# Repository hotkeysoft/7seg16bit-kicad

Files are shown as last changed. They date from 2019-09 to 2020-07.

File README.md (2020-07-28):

# Six-digit seven-segment indicator for 16 bit values
Rev A August 2019

- ATmega8535 microcontroller running at 8MHz (internal clock)
- 3x2 digit 7-segment display
- Configurable modes via jumpers:
  - Decimal / HEX mode
    - Signed Decimal (-32768-32767)
    - Unsigned Decimal (0-65535)
    - Hexadecimal (0-FFFF)
  - Latch mode
    - Latch value on L->H transition
    - Latch value on H->L transition
    - Unlatched (live display)

Images
============
|Front | Back |
|---|---|
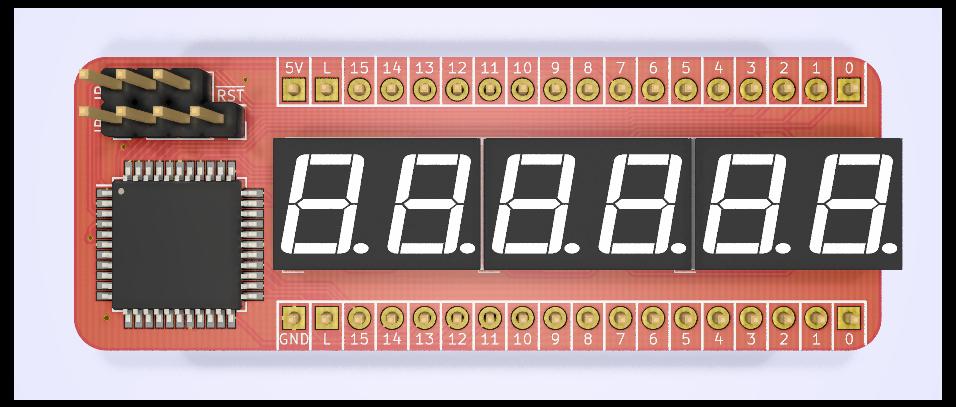
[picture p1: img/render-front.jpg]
Render Front
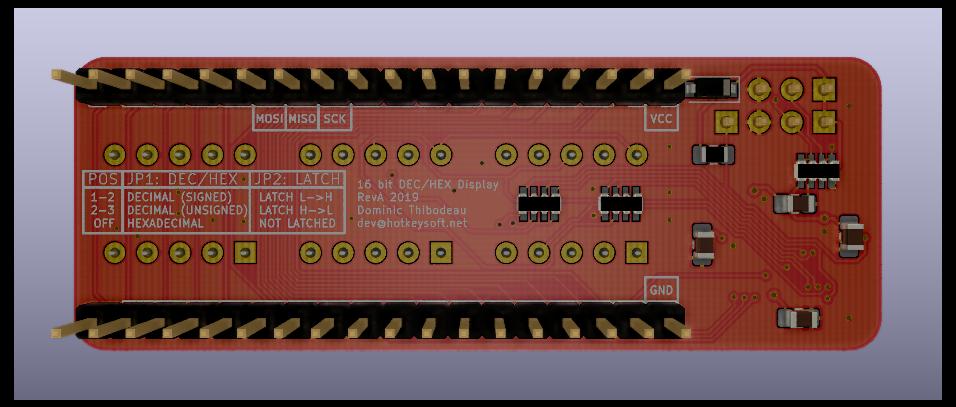
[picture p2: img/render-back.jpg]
Render Back
|||

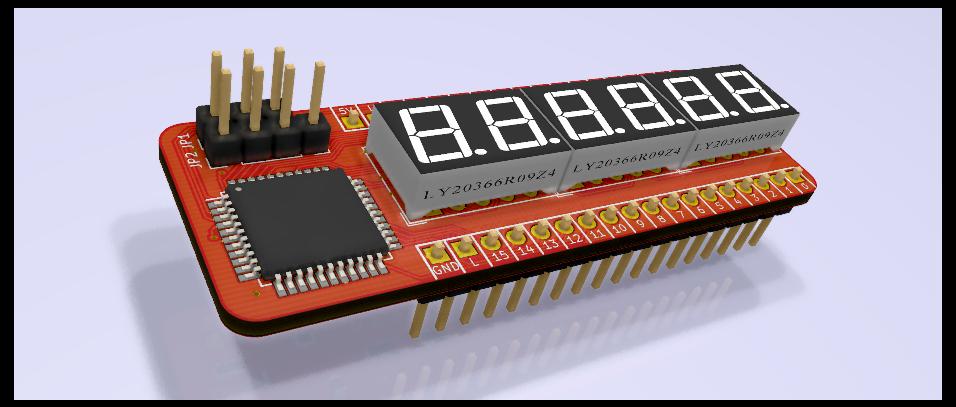
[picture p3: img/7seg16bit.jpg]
Render


### Schematics (pdf)
- [Complete schematics](./img/schema.pdf)

### PCB Images (svg)
- [Top](./img/pcb-front.svg)
- [Bottom](./img/pcb-back.svg)

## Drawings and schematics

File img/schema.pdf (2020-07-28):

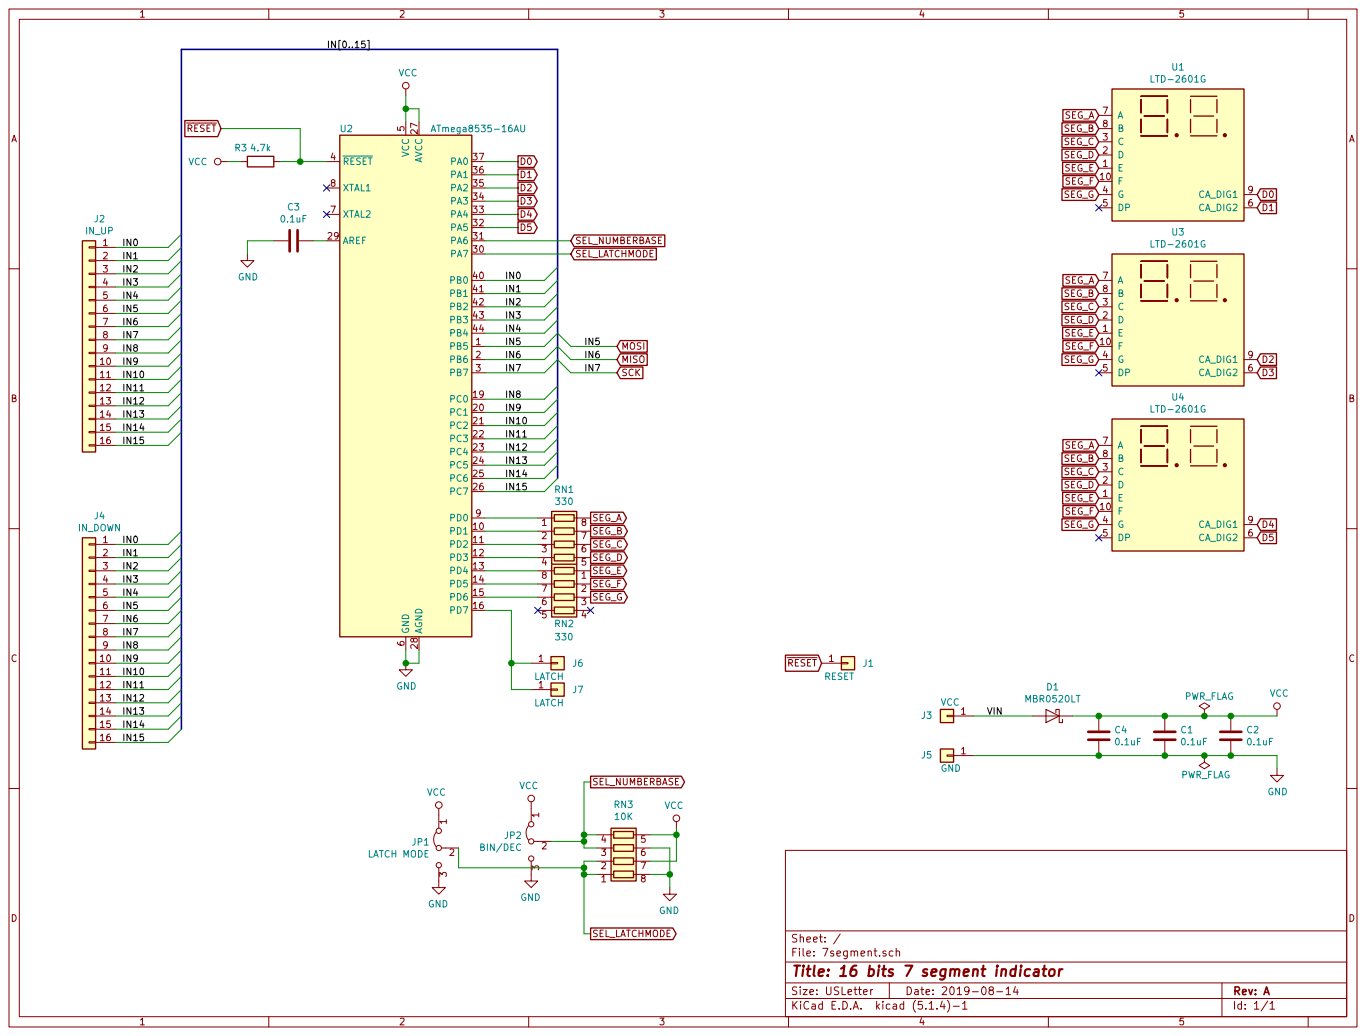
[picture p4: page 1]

Id: 1/1 Title: 16 bits 7 segment indicator

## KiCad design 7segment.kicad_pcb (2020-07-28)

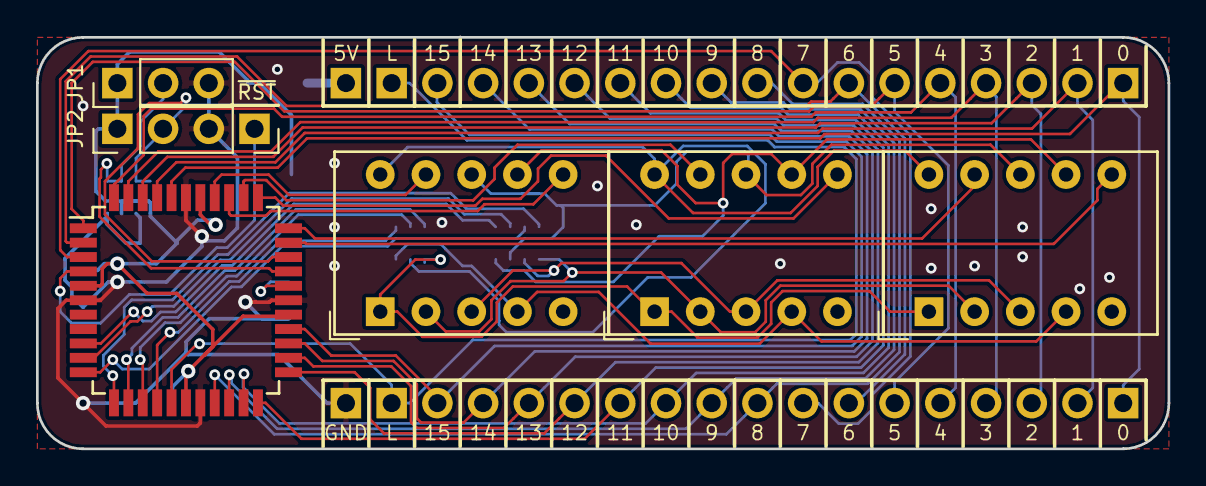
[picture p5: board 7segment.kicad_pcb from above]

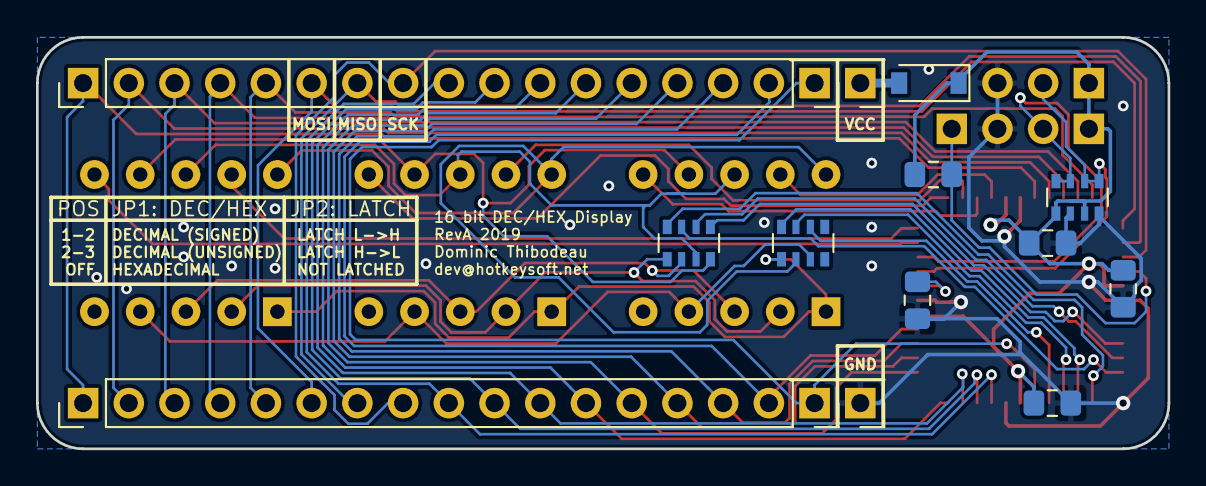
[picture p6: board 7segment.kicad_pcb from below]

Board: 2 copper layers, 62.9 x 22.9 mm, 22 parts (15 on the bottom side), 44 nets.

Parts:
C1, C2, C3, C4: 0.1uF; C_0805_2012Metric_Pad1.15x1.40mm_HandSolder
D1: MBR0520LT; D_SOD-123
J1: RESET; PinHeader_1x01_P2.54mm_Vertical
J2: IN_UP; PinHeader_1x16_P2.54mm_Vertical
J3: VCC; PinHeader_1x01_P2.54mm_Vertical
J4: IN_DOWN; PinHeader_1x16_P2.54mm_Vertical
J5: GND; PinHeader_1x01_P2.54mm_Vertical
J6, J7: LATCH; PinHeader_1x01_P2.54mm_Vertical
JP1: LATCH MODE; PinHeader_1x03_P2.54mm_Vertical
JP2: BIN/DEC; PinHeader_1x03_P2.54mm_Vertical
R3: 4.7k; R_0805_2012Metric_Pad1.15x1.40mm_HandSolder
RN1, RN2: 330; R_Array_Convex_4x0603
RN3: 10K; R_Array_Convex_4x0603
U1, U3, U4: LTD-2601G
U2: ATmega8535-16AU; TQFP-44_10x10mm_P0.8mm

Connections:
/IN0: J2.1, J4.1, U2.40
/IN1: J2.2, J4.2, U2.41
/IN2: J2.3, J4.3, U2.42
/IN3: J2.4, J4.4, U2.43
/IN4: J2.5, J4.5, U2.44
/IN8: J2.9, J4.9, U2.19
/IN9: J2.10, J4.10, U2.20
/IN10: J2.11, J4.11, U2.21
/IN11: J2.12, J4.12, U2.22
/IN12: J2.13, J4.13, U2.23
/IN13: J2.14, J4.14, U2.24
/IN14: J2.15, J4.15, U2.25
/IN15: J2.16, J4.16, U2.26
/VIN: D1.2, J3.1
D0: U1.9, U2.37
D1: U1.6, U2.36
D2: U2.35, U3.9
D3: U2.34, U3.6
D4: U2.33, U4.9
D5: U2.32, U4.6
GND: C1.2, C2.2, C3.1, C4.2, J5.1, JP1.3, JP2.3, RN3.6, RN3.8, U2.6, U2.18, U2.28, U2.39
MISO: J2.7, J4.7, U2.2
MOSI: J2.6, J4.6, U2.1
unnamed: C3.2, U2.29
unnamed: J6.1, J7.1, U2.16
unnamed: RN1.1, U2.9
unnamed: RN1.2, U2.10
unnamed: RN1.3, U2.11
unnamed: RN1.4, U2.12
unnamed: RN2.6, U2.15
unnamed: RN2.7, U2.14
unnamed: RN2.8, U2.13
SCK: J2.8, J4.8, U2.3
SEG_A: RN1.8, U1.7, U3.7, U4.7
SEG_B: RN1.7, U1.8, U3.8, U4.8
SEG_C: RN1.6, U1.3, U3.3, U4.3
SEG_D: RN1.5, U1.2, U3.2, U4.2
SEG_E: RN2.1, U1.1, U3.1, U4.1
SEG_F: RN2.2, U1.10, U3.10, U4.10
SEG_G: RN2.3, U1.4, U3.4, U4.4
SEL_LATCHMODE: JP1.2, RN3.1, RN3.2, U2.30
SEL_NUMBERBASE: JP2.2, RN3.3, RN3.4, U2.31
VCC: C1.1, C2.1, C4.1, D1.1, JP1.1, JP2.1, R3.1, RN3.5, RN3.7, U2.5, U2.17, U2.27, U2.38
~RESET: J1.1, R3.2, U2.4

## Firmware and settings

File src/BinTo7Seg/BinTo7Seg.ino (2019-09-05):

/* Binary to 7 Segment display (16 bits)
 * Rev A 
 * 2019-08-19 Dominic Thibodeau
 * 
 * Modes: Hex / Signed Decimal / Unsigned Decimal
 *        Latched / Live
 *        
 * Target: ATmega8535
 */

/*
 * IN0-IN7:  PB0-PB7
 * IN8-IN15: PC0-PC7
 * 
 * D0: PA0
 * D1: PA1
 * D2: PA2
 * D3: PA3
 * D4: PA4
 * D5: PA5
 * 
 * IN_LATCH: PD7
 * 
 * SEGA-SEGG: PD0-PD6
 * 
 * SEL_NUMBERBASE: PA6
 * SEL_LATCHMODE: PA7
 */

#define PA 0
#define PB 1
#define PC 2
#define PD 3

#define SEL_D0 24
#define SEL_D1 25
#define SEL_D2 26
#define SEL_D3 27
#define SEL_D4 28
#define SEL_D5 29

#define SEL_NUMBERBASE A6
#define SEL_LATCHMODE A7

#define IN_LATCH 15

const int digitDelay = 2;

bool triggeredOnce = false;
int lastLatchPinState;
uint16_t latchedInput = 0;

enum DIGIT {
  DIGIT_D0 = SEL_D0,
  DIGIT_D1 = SEL_D1,
  DIGIT_D2 = SEL_D2,
  DIGIT_D3 = SEL_D3,
  DIGIT_D4 = SEL_D4,
  DIGIT_D5 = SEL_D5,
};

enum LATCHMODE {
  LATCH_LH,
  LATCH_HL,
  LATCH_LIVE
};

enum NUMBERBASE {
  NB_SIGNED_DEC,
  NB_UNSIGNED_DEC,
  NB_HEX
};

LATCHMODE getLatchMode() {
  int value = analogRead(SEL_LATCHMODE);
  if (value < 300)
    return LATCH_LH;
  else if (value > 700)
    return LATCH_HL;
  else 
    return LATCH_LIVE;  
}

NUMBERBASE getNumberBase() {
  int value = analogRead(SEL_NUMBERBASE);
  if (value < 300)
    return NB_SIGNED_DEC;
  else if (value > 700)
    return NB_UNSIGNED_DEC;
  else 
    return NB_HEX;      
}

uint16_t readInput() {
  return (portRead(PC) << 8) + portRead(PB);
}

void setup() {
  // Segments
  portMode(PD, OUTPUT);
  
  // Inputs
  portMode(PB, INPUT);
  portMode(PC, INPUT);

  pinMode(SEL_D0, OUTPUT);
  pinMode(SEL_D1, OUTPUT);
  pinMode(SEL_D2, OUTPUT);
  pinMode(SEL_D3, OUTPUT);
  pinMode(SEL_D4, OUTPUT);
  pinMode(SEL_D5, OUTPUT);  

  pinMode(IN_LATCH, INPUT_PULLUP); //TODODT: remove pullup in prod  
  lastLatchPinState = digitalRead(IN_LATCH);
}

const PROGMEM byte digits[17] = {
  0b00111111, // 0
  0b00000110, // 1
  0b01011011, // 2  
  0b01001111, // 3
  0b01100110, // 4
  0b01101101, // 5
  0b01111101, // 6
  0b00000111, // 7 
  0b01111111, // 8
  0b01101111, // 9 
  0b01110111, // A
  0b01111100, // b
  0b00111001, // C
  0b01011110, // d
  0b01111001, // E
  0b01110001, // F
  0b01000000  // -
};

void outputBlank(DIGIT pos) {
  clearDigits();
  portWrite(PD, 255);
  selectDigit(pos);
}

void outputMinus(DIGIT pos) {
  clearDigits();
  portWrite(PD, ~pgm_read_byte_near(digits + 16));
  selectDigit(pos);  
}

void outputDigit(const byte digit, DIGIT pos) {
  clearDigits();
  if (digit > 15) return;
  portWrite(PD, ~pgm_read_byte_near(digits + digit));
  selectDigit(pos);  
}

void clearDigits() {
  digitalWrite(SEL_D0, LOW);
  digitalWrite(SEL_D1, LOW);
  digitalWrite(SEL_D2, LOW);
  digitalWrite(SEL_D3, LOW);
  digitalWrite(SEL_D4, LOW);
  digitalWrite(SEL_D5, LOW);  
}

void selectDigit(DIGIT digit) {
  digitalWrite(digit, HIGH);
}

void outputNumberHex(const uint16_t number) {
  outputBlank(DIGIT_D0);
  delay(digitDelay);

  outputBlank(DIGIT_D1);
  delay(digitDelay);
 
  outputDigit(number >> 12, DIGIT_D2);
  delay(digitDelay);

  outputDigit((number >> 8) & 0x0F, DIGIT_D3);
  delay(digitDelay);
  
  outputDigit((number >> 4) & 0x0F, DIGIT_D4);
  delay(digitDelay);

  outputDigit(number&0x0F, DIGIT_D5);
  delay(digitDelay);
}

void outputNumberUnsignedDecimal(uint16_t number) {
  if (number > 9999) {
    outputDigit(number/10000, DIGIT_D1);
  }
  else {
    outputBlank(DIGIT_D1);
  }
  delay(digitDelay);  
  
  if (number > 999) {
    outputDigit((number/1000)%10, DIGIT_D2);
  } else {
    outputBlank(DIGIT_D2);    
  }
  delay(digitDelay);      
  
  if (number > 99) {
    outputDigit((number/100)%10, DIGIT_D3);
  } else {
    outputBlank(DIGIT_D3);    
  }
  delay(digitDelay);    
  
  if (number > 9) {
    outputDigit((number/10)%10, DIGIT_D4);
  } else {
    outputBlank(DIGIT_D4);
  }
  delay(digitDelay);

  outputDigit(number%10, DIGIT_D5);
  delay(digitDelay);
}

void outputNumberSignedDecimal(uint16_t number) {
  if (number > 32767) {
    uint16_t unsignedValue = -number;

    outputNumberUnsignedDecimal(unsignedValue);  

    if (unsignedValue > 9999)
      outputMinus(DIGIT_D0);
    else if (unsignedValue > 999)
      outputMinus(DIGIT_D1);
    else if (unsignedValue > 99)
      outputMinus(DIGIT_D2);
    else if (unsignedValue > 9)
      outputMinus(DIGIT_D3);
    else 
      outputMinus(DIGIT_D4);

    delay(digitDelay);      
  } else {
    outputNumberUnsignedDecimal(number);
  }
}

void outputNumber(uint16_t number) {
  switch(getNumberBase()) {
    case NB_SIGNED_DEC:
      outputNumberSignedDecimal(number);
      break;
    case NB_UNSIGNED_DEC:
      outputNumberUnsignedDecimal(number);
      break;
    default:
      outputNumberHex(number);
  }
}

void loop() { 
  clearDigits();
  
  LATCHMODE latchMode = getLatchMode();

  if (latchMode != LATCH_LIVE) {
    bool triggered = false;
    int currLatchState = digitalRead(IN_LATCH);
    triggered = ((latchMode == LATCH_LH) && !lastLatchPinState && currLatchState) || 
      ((latchMode == LATCH_HL) && lastLatchPinState && !currLatchState);
    lastLatchPinState = currLatchState;

    if (triggered) {
      triggeredOnce = true;
      latchedInput = readInput();;
    }
    if (triggeredOnce) {
      outputNumber(latchedInput);
    }
  } else {   
    outputNumber(readInput());
  }
}

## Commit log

2019-08-23 Add PCB Fabrication zip files
2019-09-05 Fixed negative number issue. Improved uneven brightness and ghost segments
    [BinTo7Seg.ino]
2019-10-21 update kicad
    [7segment.sch]
2020-07-28 Cleanup, added commonlib
    [7segment.kicad_pcb]
